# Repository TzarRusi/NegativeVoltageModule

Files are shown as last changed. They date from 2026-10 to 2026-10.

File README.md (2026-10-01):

Negative Voltage Module — LT3090

**Автор: Владислав Чернухин** · [Инженерное портфолио](https://github.com/TzarRusi)

Специализированная четырёхканальная плата отрицательного питания для лабораторных задач. Мой вклад — разработка схемотехники и топологии платы на LT3090. В репозитории собраны редактируемые исходники, схема, BOM и материалы конструктива.

## Фотография платы

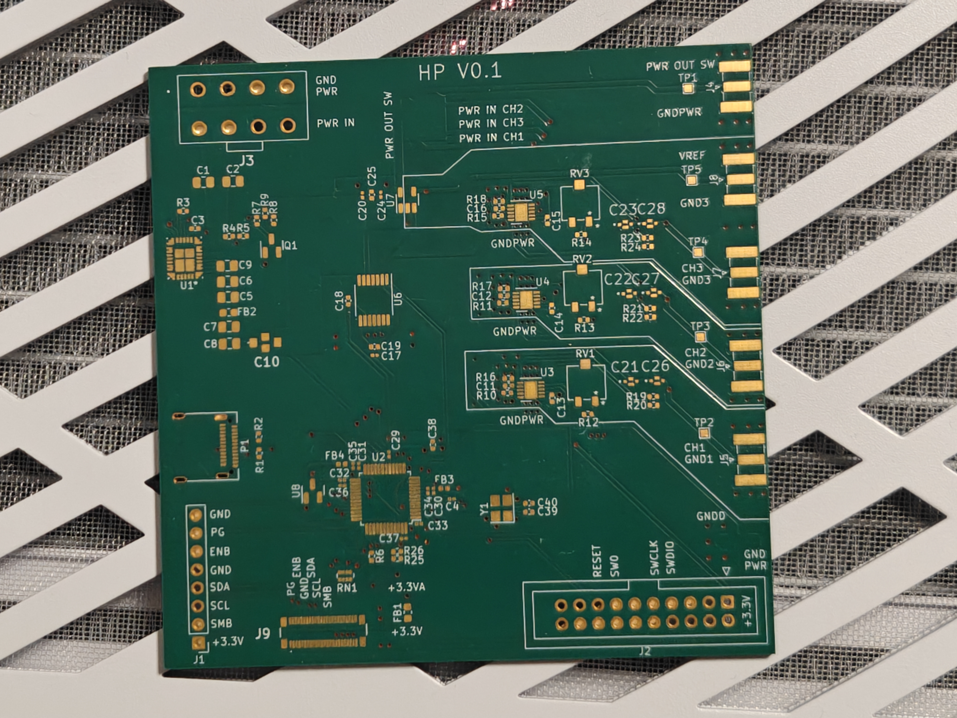
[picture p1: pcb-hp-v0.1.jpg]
Печатная плата HP V0.1 до монтажа компонентов

<sub>Фото платы с маркировкой HP V0.1, до монтажа компонентов. Разводка отличается от архивной CAD-ревизии, представленной ниже.</sub>

## CAD-ревизия

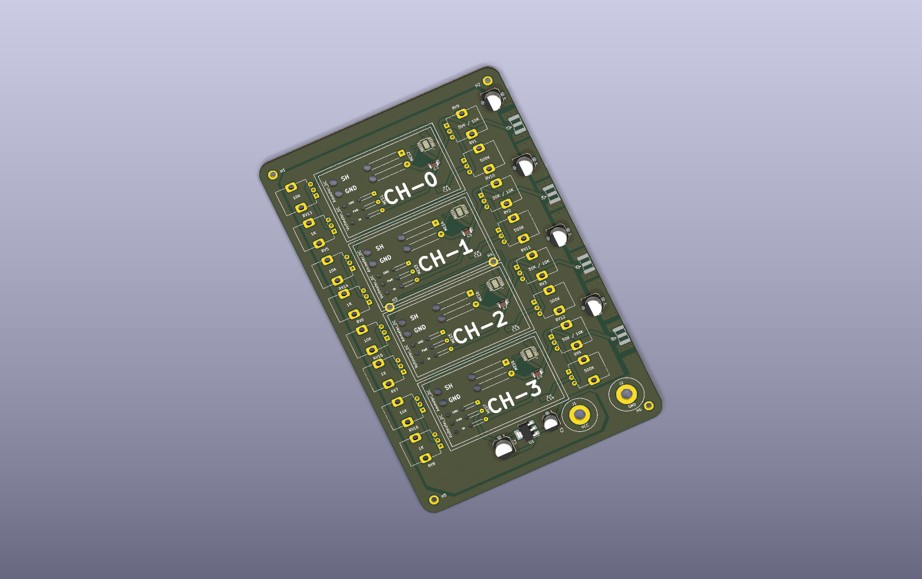
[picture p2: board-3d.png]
CAD-рендер печатной платы

<sub>Рендер из исходного файла KiCad. Это визуализация PCB; часть компонентов не имеет подключённых 3D-моделей.</sub>

## Устройство

| Узел | Реализация в проекте |
|---|---|
| Каналы | 4 повторяемых иерархических листа Channel0–Channel3 |
| Регулятор | LT3090EMSE_PBF, корпус MSOP-12 с теплоотводящей площадкой |
| Настройка | Потенциометры в каждом канале |
| Контроль | Подключения внешних вольтметров и амперметров |
| Выходы | 4 коаксиальных разъёма SMA |
| PCB | 2 медных слоя; толщина платы в исходнике 1,57 мм |
| Конструктив | STEP-модели платы и исходники деталей/сборок SolidWorks |

## Схемы и разводка

[Общая схема](NegativeVoltageModule.svg) · [Схема одного канала](NegativeVoltageModule-Channel0.svg) · [Верхний слой PCB](pcb-top.svg)

Схема канала LT3090

## Открыть проект

1. Скачайте репозиторий целиком и откройте `NegativeVoltageModule.kicad_pro` в KiCad (исходный формат — KiCad 7; просмотр и экспорт проверены в KiCad 10).
2. Для редактирования библиотечных компонентов распакуйте `custom-library.zip` **в корень репозитория**, сохранив структуру. В архиве находятся локальные таблицы библиотек и посадочное место; символ LT3090 уже включён в репозиторий.
3. Если старые 3D-ссылки не разрешаются, задайте `KICAD6_3DMODEL_DIR` на каталог стандартных 3D-моделей установленного KiCad.
4. Конструктив находится в `mechanical-source.zip`. Для сборок SolidWorks может потребоваться переуказание ссылок на файлы деталей и платы.

| Файлы | Содержание |
|---|---|
| `*.kicad_pro`, `*.kicad_pcb`, `*.kicad_sch` | Проект, плата и иерархическая схема |
| `NegativeVoltageModule.csv` | Исходный BOM; разделитель `;` |
| `LT3090EMSE_PBF.kicad_sym`, `MSOP-12_MSE.kicad_mod` | Пользовательский символ и посадочное место |
| `custom-library.zip` | Локальная конфигурация библиотек для переноса проекта |
| `mechanical-source.zip` | STEP, SLDPRT и SLDASM |
| `manufacturing-review.zip` | Gerber, Excellon Drill, позиции компонентов и BOM для инженерной проверки |
| `VERIFICATION.md` | Результаты проверки и границы готовности |

## Статус

Разработка платы завершена. Исходные схемы, PCB и производственные файлы опубликованы в репозитории.

Справочная документация: [LT3090 — Analog Devices](https://www.analog.com/en/products/lt3090.html). Параметры микросхемы не следует приравнивать к измеренным параметрам всей платы.

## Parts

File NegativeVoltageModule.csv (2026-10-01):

Идентиф. | Обозначение | Посад.место | Количество | Значение | Поставщик и справка
1 | J1 | MountingHole_4.3mm_M4_ISO7380_Pad | 1 | VCC
2 | C14,C13,C11,C12 | C_0402_1005Metric_Pad0.74x0.62mm_HandSolder | 4 | 0.1u
3 | MES5,MES3,MES1,MES7 | SolderWire-0.1sqmm_1x03_P3.6mm_D0.4mm_OD1mm_Relief2x | 4 | Voltmeter_DC
4 | C7,C9,C3,C5 | C_1206_3216Metric_Pad1.33x1.80mm_HandSolder | 4 | 10u
5 | U4,U5,U2,U3 | MSOP-12_MSE | 4 | LT3090EMSE_PBF
6 | C8,C4,C6,C10,C2 | CP_Elec_6.3x5.4 | 5 | 22u 35V
7 | J2 | MountingHole_4.3mm_M4_ISO7380_Pad | 1 | GND
8 | H5,H6,H3,H2,H1,H4 | MountingHole_2.2mm_M2_ISO7380_Pad | 6 | MountingHole_Pad
9 | RV1,RV3,RV4,RV2 | Potentiometer_Alps_RK09K_Single_Vertical | 4 | Rv09 500k
10 | MES6,MES4,MES2,MES8 | SolderWire-0.5sqmm_1x02_P4.8mm_D0.9mm_OD2.3mm_Relief2x | 4 | Ammeter_DC
11 | J6,J5,J4,J3 | SMA_Samtec_SMA-J-P-X-ST-EM1_EdgeMount | 4 | Conn_Coaxial
12 | RV14,RV12,RV11,RV10,RV16,RV13,RV9,RV15 | Potentiometer_Alps_RK09K_Single_Vertical | 8 | Rv09 10k
13 | U1 | SOT-223-3_TabPin2 | 1 | AMS1117-5.0
14 | RV6,RV5,RV8,RV7 | Potentiometer_Alps_RK09K_Single_Vertical | 4 | R-09 1K
15 | C1 | CP_Elec_5x5.4 | 1 | 10u 35V

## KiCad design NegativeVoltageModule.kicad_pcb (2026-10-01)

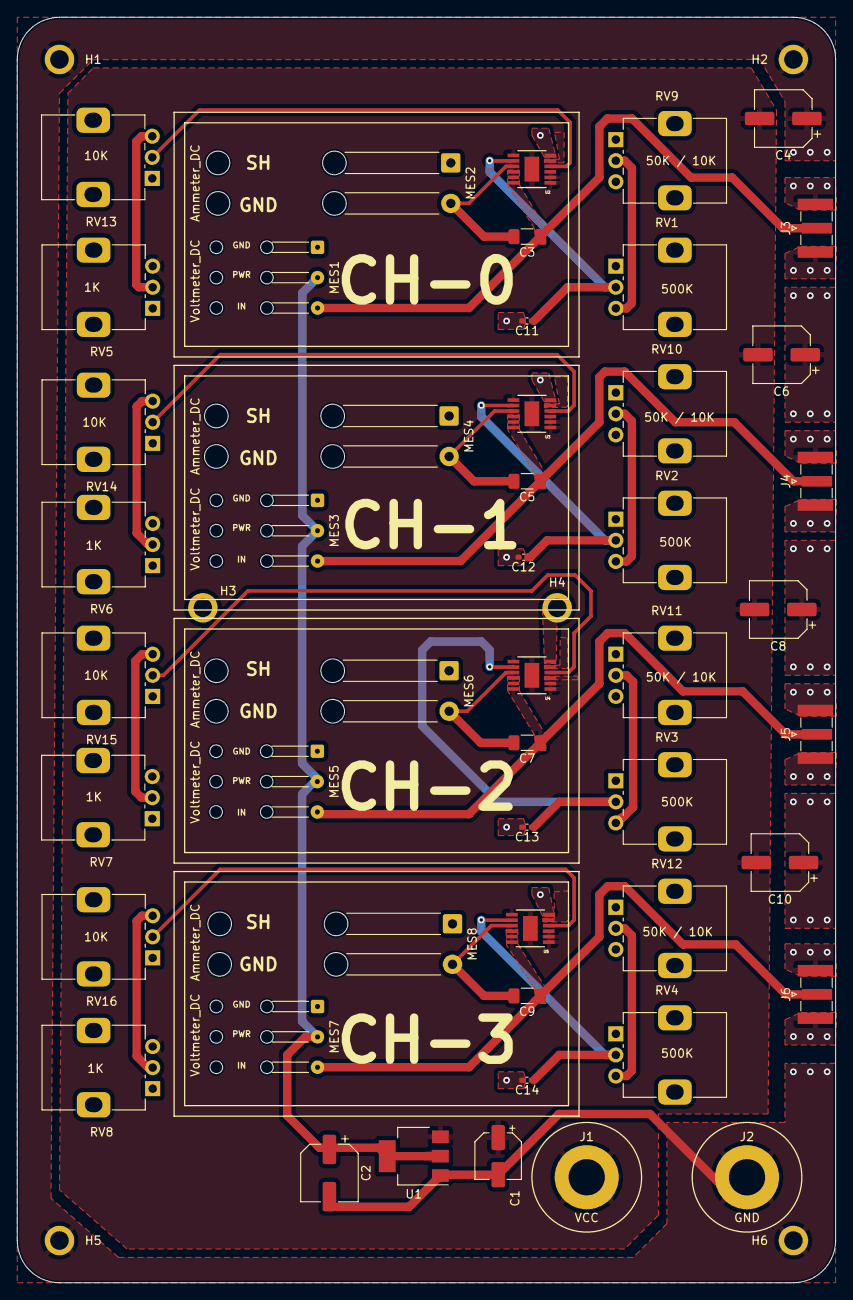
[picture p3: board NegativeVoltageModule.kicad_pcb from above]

Board: 2 copper layers, 97.0 x 150.0 mm, 55 parts (0 on the bottom side), 27 nets.

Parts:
C1: 10u 35V; CP_Elec_5x5.4
C2, C4, C6, C8, C10: 22u 35V; CP_Elec_6.3x5.4
C3, C5, C7, C9: 10u; C_1206_3216Metric_Pad1.33x1.80mm_HandSolder
C11, C12, C13, C14: 0.1u; C_0402_1005Metric_Pad0.74x0.62mm_HandSolder
H1, H2, H3, H4, H5, H6: MountingHole_Pad; MountingHole_2.2mm_M2_ISO7380_Pad
J1: VCC; MountingHole_4.3mm_M4_ISO7380_Pad
J2: GND; MountingHole_4.3mm_M4_ISO7380_Pad
J3, J4, J5, J6: Conn_Coaxial; SMA_Samtec_SMA-J-P-X-ST-EM1_EdgeMount
MES1, MES3, MES5, MES7: Voltmeter_DC; SolderWire-0.1sqmm_1x03_P3.6mm_D0.4mm_OD1mm_Relief2x
MES2, MES4, MES6, MES8: Ammeter_DC; SolderWire-0.5sqmm_1x02_P4.8mm_D0.9mm_OD2.3mm_Relief2x
RV1, RV2, RV3, RV4: Rv09 500k; Potentiometer_Alps_RK09K_Single_Vertical
RV5, RV6, RV7, RV8: R-09 1K; Potentiometer_Alps_RK09K_Single_Vertical
RV9, RV10, RV11, RV12, RV13, RV14, RV15, RV16: Rv09 10k; Potentiometer_Alps_RK09K_Single_Vertical
U1: AMS1117-5.0; SOT-223-3_TabPin2
U2, U3, U4, U5: LT3090EMSE_PBF; MSOP-12_MSE

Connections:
+5V: C2.1, MES1.2 (PWR), MES3.2 (PWR), MES5.2 (PWR), MES7.2 (PWR), U1.2 (VO)
/Channel0/OUT: C3.1, J3.1 (In), MES1.3 (+), U2.10 (OUT_2), U2.11 (OUT_3), U2.12 (OUT)
/Channel0/SH: J3.2 (Ext), MES2.1 (+)
/Channel1/OUT: C5.1, J4.1 (In), MES3.3 (+), U3.10 (OUT_2), U3.11 (OUT_3), U3.12 (OUT)
/Channel1/SH: J4.2 (Ext), MES4.1 (+)
/Channel2/OUT: C7.1, J5.1 (In), MES5.3 (+), U4.10 (OUT_2), U4.11 (OUT_3), U4.12 (OUT)
/Channel2/SH: J5.2 (Ext), MES6.1 (+)
/Channel3/OUT: C9.1, J6.1 (In), MES7.3 (+), U5.10 (OUT_2), U5.11 (OUT_3), U5.12 (OUT)
/Channel3/SH: J6.2 (Ext), MES8.1 (+)
GND: C1.2, C2.2, C3.2, C4.1, C5.2, C6.1, C7.2, C8.1, C9.2, C10.1, C11.2, C12.2, C13.2, C14.2, H1.1, H2.1, H3.1, H4.1, H5.1, H6.1, J2.1, MES1.1 (-), MES2.2 (-), MES3.1 (-), MES4.2 (-), MES5.1 (-), MES6.2 (-), MES7.1 (-), MES8.2 (-), RV9.3, RV10.3, RV11.3, RV12.3, U1.1 (GND), U2.6 (IMONN), U2.9 (GND), U3.6 (IMONN), U3.9 (GND), U4.6 (IMONN), U4.9 (GND), U5.6 (IMONN), U5.9 (GND)
unnamed: RV1.3, RV9.2
unnamed: RV2.3, RV10.2
unnamed: RV3.3, RV11.2
unnamed: RV4.3, RV12.2
unnamed: RV5.2, RV13.3
unnamed: RV6.2, RV14.3
unnamed: RV7.2, RV15.3
unnamed: RV8.2, RV16.3
unnamed: RV13.2, U2.4 (ILIM)
unnamed: C11.1, RV1.2, U2.8 (SET)
unnamed: RV14.2, U3.4 (ILIM)
unnamed: C12.1, RV2.2, U3.8 (SET)
unnamed: RV15.2, U4.4 (ILIM)
unnamed: C13.1, RV3.2, U4.8 (SET)
unnamed: RV16.2, U5.4 (ILIM)
unnamed: C14.1, RV4.2, U5.8 (SET)
VCC: C1.1, C4.2, C6.2, C8.2, C10.2, J1.1, RV5.3, RV6.3, RV7.3, RV8.3, U1.3 (VI), U2.1 (IN_2), U2.2 (IN_3), U2.3 (IN_4), U2.5 (IMONP), U2.7 (*SHDN), U2.13 (IN), U3.1 (IN_2), U3.2 (IN_3), U3.3 (IN_4), U3.5 (IMONP), U3.7 (*SHDN), U3.13 (IN), U4.1 (IN_2), U4.2 (IN_3), U4.3 (IN_4), U4.5 (IMONP), U4.7 (*SHDN), U4.13 (IN), U5.1 (IN_2), U5.2 (IN_3), U5.3 (IN_4), U5.5 (IMONP), U5.7 (*SHDN), U5.13 (IN)

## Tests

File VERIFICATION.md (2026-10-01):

# Проверка архивной ревизии

Дата: 2026-10-01. Инструмент: KiCad CLI 10.0. Проверки выполнены по опубликованному исходнику, без изменения схемотехники и разводки.

- Иерархическая схема: экспортированы все 5 листов SVG.
- PCB: успешно сформированы SVG и 3D-рендер.
- DRC: 72 замечания; неподключённых элементов — 0.

| Тип | Уровень | Количество |
|---|---|---:|
| `lib_footprint_issues` | warning | 8 |
| `lib_footprint_mismatch` | warning | 17 |
| `silk_over_copper` | warning | 6 |
| `starved_thermal` | error | 16 |
| `text_height` | warning | 16 |
| `text_thickness` | warning | 4 |
| `zones_intersect` | error | 5 |

Часть библиотечных предупреждений зависит от установленной версии библиотек. Ошибки `starved_thermal` и `zones_intersect` требуют отдельной проверки и исправления перед изготовлением. Проверка соответствия PCB схеме (schematic parity) не выполнялась.

Gerber/Drill/Pick&Place — экспорт архивной ревизии, не утверждённый производственный релиз. Наличие экспорта не означает прохождение DFM. Визуализация не подтверждает монтаж и электрические характеристики.

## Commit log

2026-10-01 Publish LT3090 hardware portfolio: KiCad sources, CAD views and review exports
    [NegativeVoltageModule.csv, NegativeVoltageModule.kicad_pcb, NegativeVoltageModule.kicad_sch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]
2026-10-01 Add HP V0.1 PCB photograph to project README
